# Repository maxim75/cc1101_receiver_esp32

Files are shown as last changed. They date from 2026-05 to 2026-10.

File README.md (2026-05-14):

# CC1101 + nRF24L01 Dual RF Receiver (ESP32-S3)

ESP32-S3 firmware that receives RF packets from two radios simultaneously and displays decoded data on an SH1107 128×128 OLED and serial monitor.

- **CC1101** — 433.92 MHz OOK packets from an ATtiny3226 transmitter (ELECHOUSE SmartRC-compatible protocol)
- **nRF24L01** — 2.4 GHz packets at 250 kbps, PA MAX

## Hardware

**Board:** ESP32-S3-DevKitC-1 (16 MB flash, PSRAM, native USB CDC)

### Wiring

| Peripheral | Signal | GPIO |
|---|---|---|
| CC1101 | SCK | 12 (FSPI/SPI2) |
| | MOSI | 11 |
| | MISO | 13 |
| | CSN | 10 |
| | GDO0 | 2 (interrupt) |
| nRF24L01 | SCK | 14 (HSPI/SPI3) |
| | MOSI | 1 |
| | MISO | 21 |
| | CSN | 6 |
| | CE | 5 |
| | IRQ | 4 (wired, not used) |
| SH1107 | SDA | 8 |
| | SCL | 9 |

All peripherals: VCC → 3.3 V, GND → GND

## Build & Flash

Requires [PlatformIO](https://platformio.org/).

```bash
# Build only
pio run

# Flash
pio run --target upload

# Flash and open serial monitor
pio run --target upload && pio device monitor

# Serial monitor only (115200 baud)
pio device monitor
```

## Dependencies

Managed automatically by PlatformIO:

| Library | Purpose |
|---|---|
| `jgromes/RadioLib` | CC1101 driver |
| `nrf24/RF24` | nRF24L01 driver |
| `olikraus/U8g2` | SH1107 OLED driver |
| `bblanchon/ArduinoJson` | JSON (available, not yet used) |

## How It Works

All firmware lives in `src/main.cpp`.

**CC1101** — interrupt-driven: GDO0 RISING edge sets a flag; `loop()` reads the packet with RadioLib, re-arms `startReceive()`, then calls `getRSSI()`.

**nRF24L01** — polled: `loop()` calls `nrf24.available()` each iteration; no re-arm needed.

Both radios share the same `PacketInfo` struct (`source`, hex, ASCII, RSSI, count). After each packet the OLED and serial monitor are updated; the OLED header shows which radio sourced the last packet.

**SPI:** CC1101 on FSPI (`SPI`), nRF24 on HSPI (`hspi`) — separate buses, no CS conflicts.

## Serial Output

Each received packet is logged at 115200 baud:

```
[CC1101] #1 | RSSI: -72 dBm | HEX: D3 91 04 AB CD | ASCII: ...
[nRF24]  #2 | HEX: 48 65 6C 6C 6F     | ASCII: Hello
```

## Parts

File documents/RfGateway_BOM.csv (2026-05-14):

Reference | Qty | Value | DNP | Exclude from BOM | Exclude from Board | Footprint | Datasheet
C1,C2,C3,C11,C12,C13 | 6 | 100nF |  |  |  | Capacitor_SMD:C_0805_2012Metric_Pad1.18x1.45mm_HandSolder
C4 | 1 | 22uF |  |  |  | Capacitor_SMD:C_0805_2012Metric_Pad1.18x1.45mm_HandSolder
C5,C6,C7,C8,C9,C10 | 6 | 1uF |  |  |  | Capacitor_SMD:C_0805_2012Metric_Pad1.18x1.45mm_HandSolder
C14,C15,C16 | 3 | 10uF |  |  |  | PCM_Capacitor_THT_AKL:CP_Radial_D5.0mm_P2.00mm
C17,C18 | 2 | 15pF |  |  |  | Capacitor_SMD:C_0805_2012Metric_Pad1.18x1.45mm_HandSolder
CN1 | 1 | I2C |  |  |  | easyeda2kicad:CONN-SMD_HCZZ0451-4
CN2 | 1 | X2026WV-2*02-N0SN |  |  |  | easyeda2kicad:CONN-TH_X2026WV-2X02-N0SN | https://lcsc.com/product-detail/Wire-To-Board-Wire-To-Wire-Connector_XKB-Enterprise-X2026WV-2-02-N0SN_C406181.html
CN4 | 1 | HX-PH2.0-6AWB |  |  |  | easyeda2kicad:CONN-SMD_HX-PH2.0-6AWB
D1 | 1 | SS14 |  |  |  | PCM_Diode_SMD_AKL:D_SMA | https://www.tme.eu/Document/39e1c2d2c354f63d74e9a2edb2156b4b/SS14-E3_61T.pdf
FPC1 | 1 | PH-2PWB |  |  |  | easyeda2kicad:FPC-SMD_2P-P2.00_DEALON_PH-2PWB
R1,R2 | 2 | 5.1K |  |  |  | Resistor_SMD:R_0805_2012Metric_Pad1.20x1.40mm_HandSolder
R3,R4,R5 | 3 | 10K |  |  |  | Resistor_SMD:R_0805_2012Metric_Pad1.20x1.40mm_HandSolder
SW1 | 1 | FLASH |  |  |  | easyeda2kicad:SW-SMD_4P-L4.5-W4.5-P3.00-LS7.5
SW2 | 1 | RESET |  |  |  | easyeda2kicad:SW-SMD_4P-L4.5-W4.5-P3.00-LS7.5
U1 | 1 | ESP32-S3-WROOM-2 |  |  |  | RF_Module:ESP32-S3-WROOM-2 | https://www.espressif.com/sites/default/files/documentation/esp32-s3-wroom-2_datasheet_en.pdf
U2 | 1 | E01C-ML01SP4 |  |  |  | easyeda2kicad:COMM-SMD_E01C-ML01SP4
U3 | 1 | E07-400M10S |  |  |  | easyeda2kicad:COMM-SMD_E07-400M10S
U4 | 1 | GT-USB-7010ASV |  |  |  | easyeda2kicad:USB-C-SMD_G-SWITCH_GT-USB-7010ASV
U5,U6 | 2 | MCP1700T-3302E-TT |  |  |  | PCM_Package_TO_SOT_SMD_AKL:SOT-23 | https://ww1.microchip.com/downloads/en/DeviceDoc/MCP1700-Low-Quiescent-Current-LDO-20001826E.pdf
U7 | 1 | ME6211C33M5 |  |  |  | Package_TO_SOT_SMD:SOT-23-5 | https://www.lcsc.com/datasheet/lcsc_datasheet_2304140030_MICRONE-Nanjing-Micro-One-Elec-ME6211C33R5G_C235316.pdf
U8 | 1 | E220-900T22S |  |  |  | easyeda2kicad:WIRELM-SMD_E220-900T22S | https://lcsc.com/product-detail/Wireless-Modules_Chengdu-Ebyte-Elec-Tech-E220-900T22S_C970285.html
Y1 | 1 | 32K |  |  |  | Crystal:Crystal_AT310_D3.0mm_L10.0mm_Horizontal

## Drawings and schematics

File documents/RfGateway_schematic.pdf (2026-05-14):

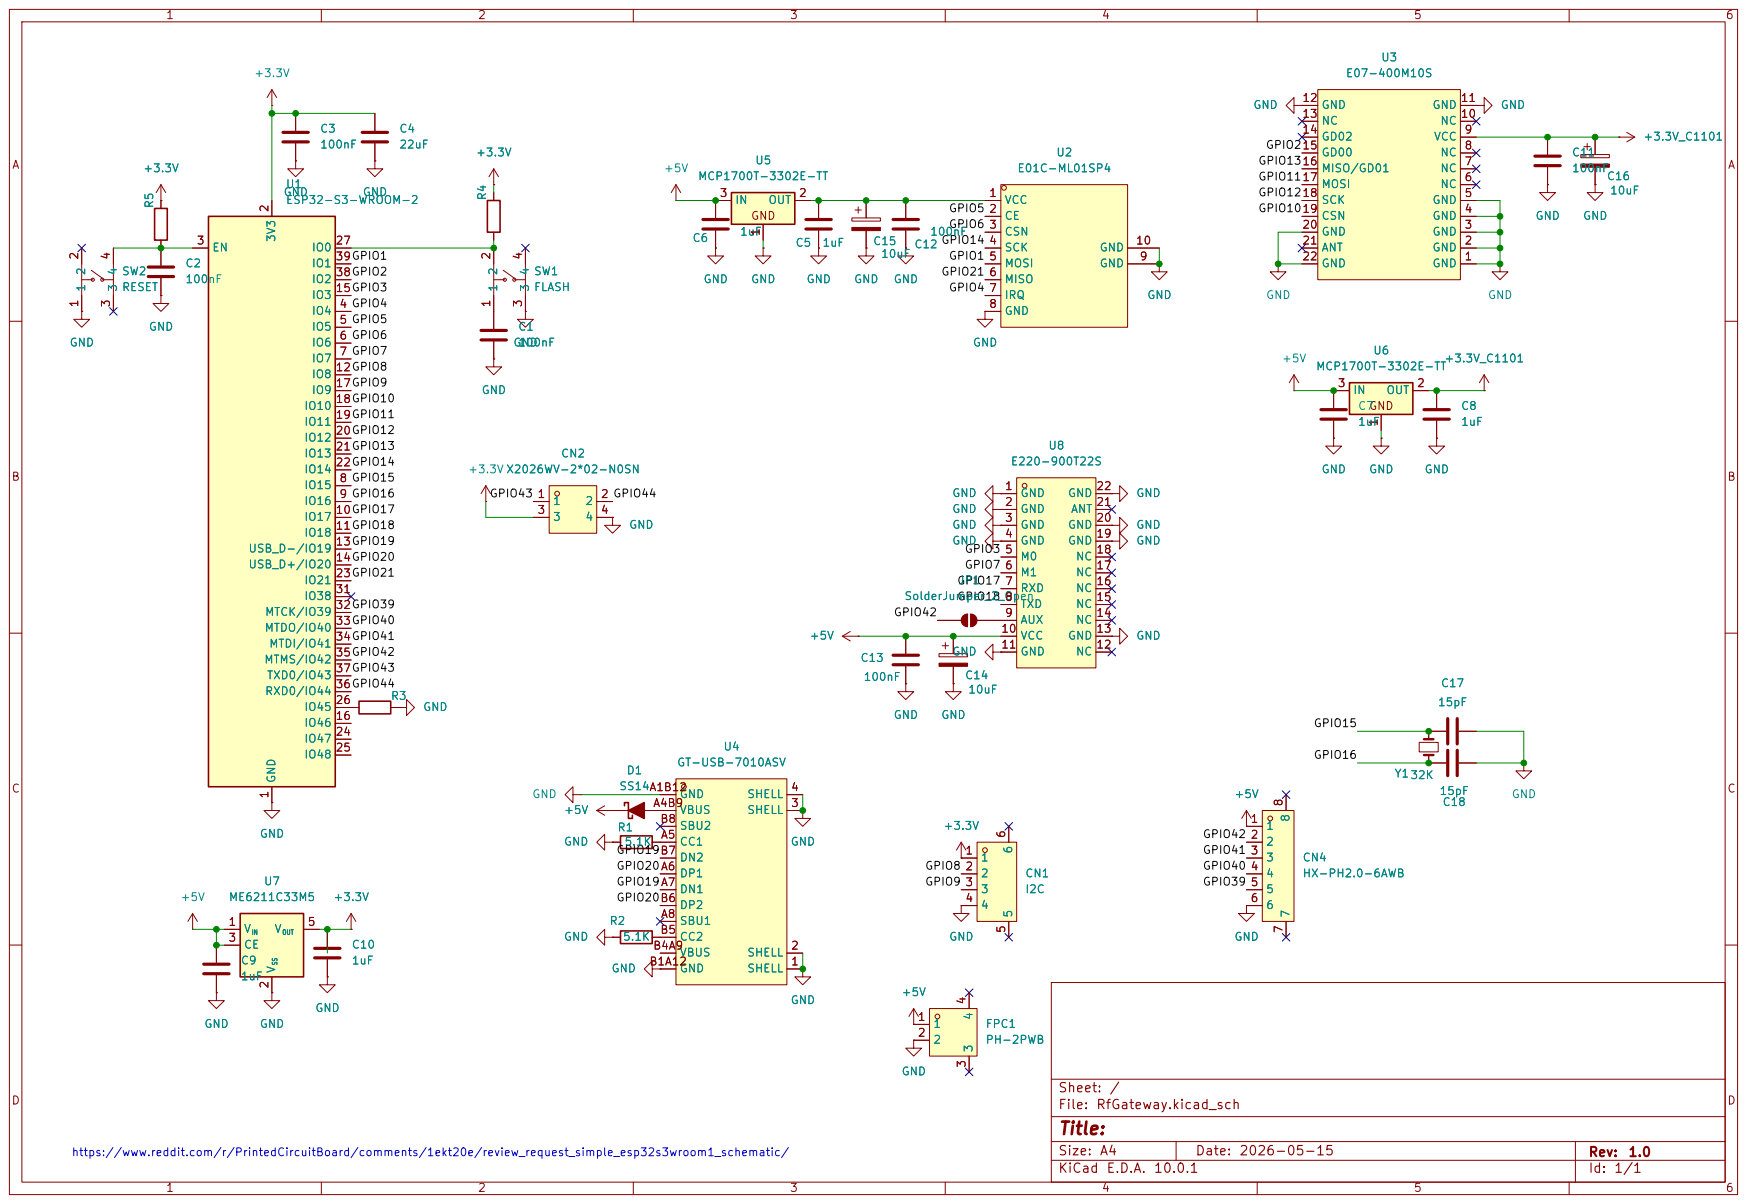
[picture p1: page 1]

IO38 31 MTCK/IO39 32 MTDO/IO40 33 MTDI/IO41 34 MTMS/IO42 35 RXD0/IO44 36 TXD0/IO43 37

https://www.reddit.com/r/PrintedCircuitBoard/comments/1ekt20e/review_request_simple_esp32s3wroom1_schematic/ +3.3V C10

Size: A4 | Rev: 1.0
KiCad E.D.A. 10.0.1 | Id: 1/1

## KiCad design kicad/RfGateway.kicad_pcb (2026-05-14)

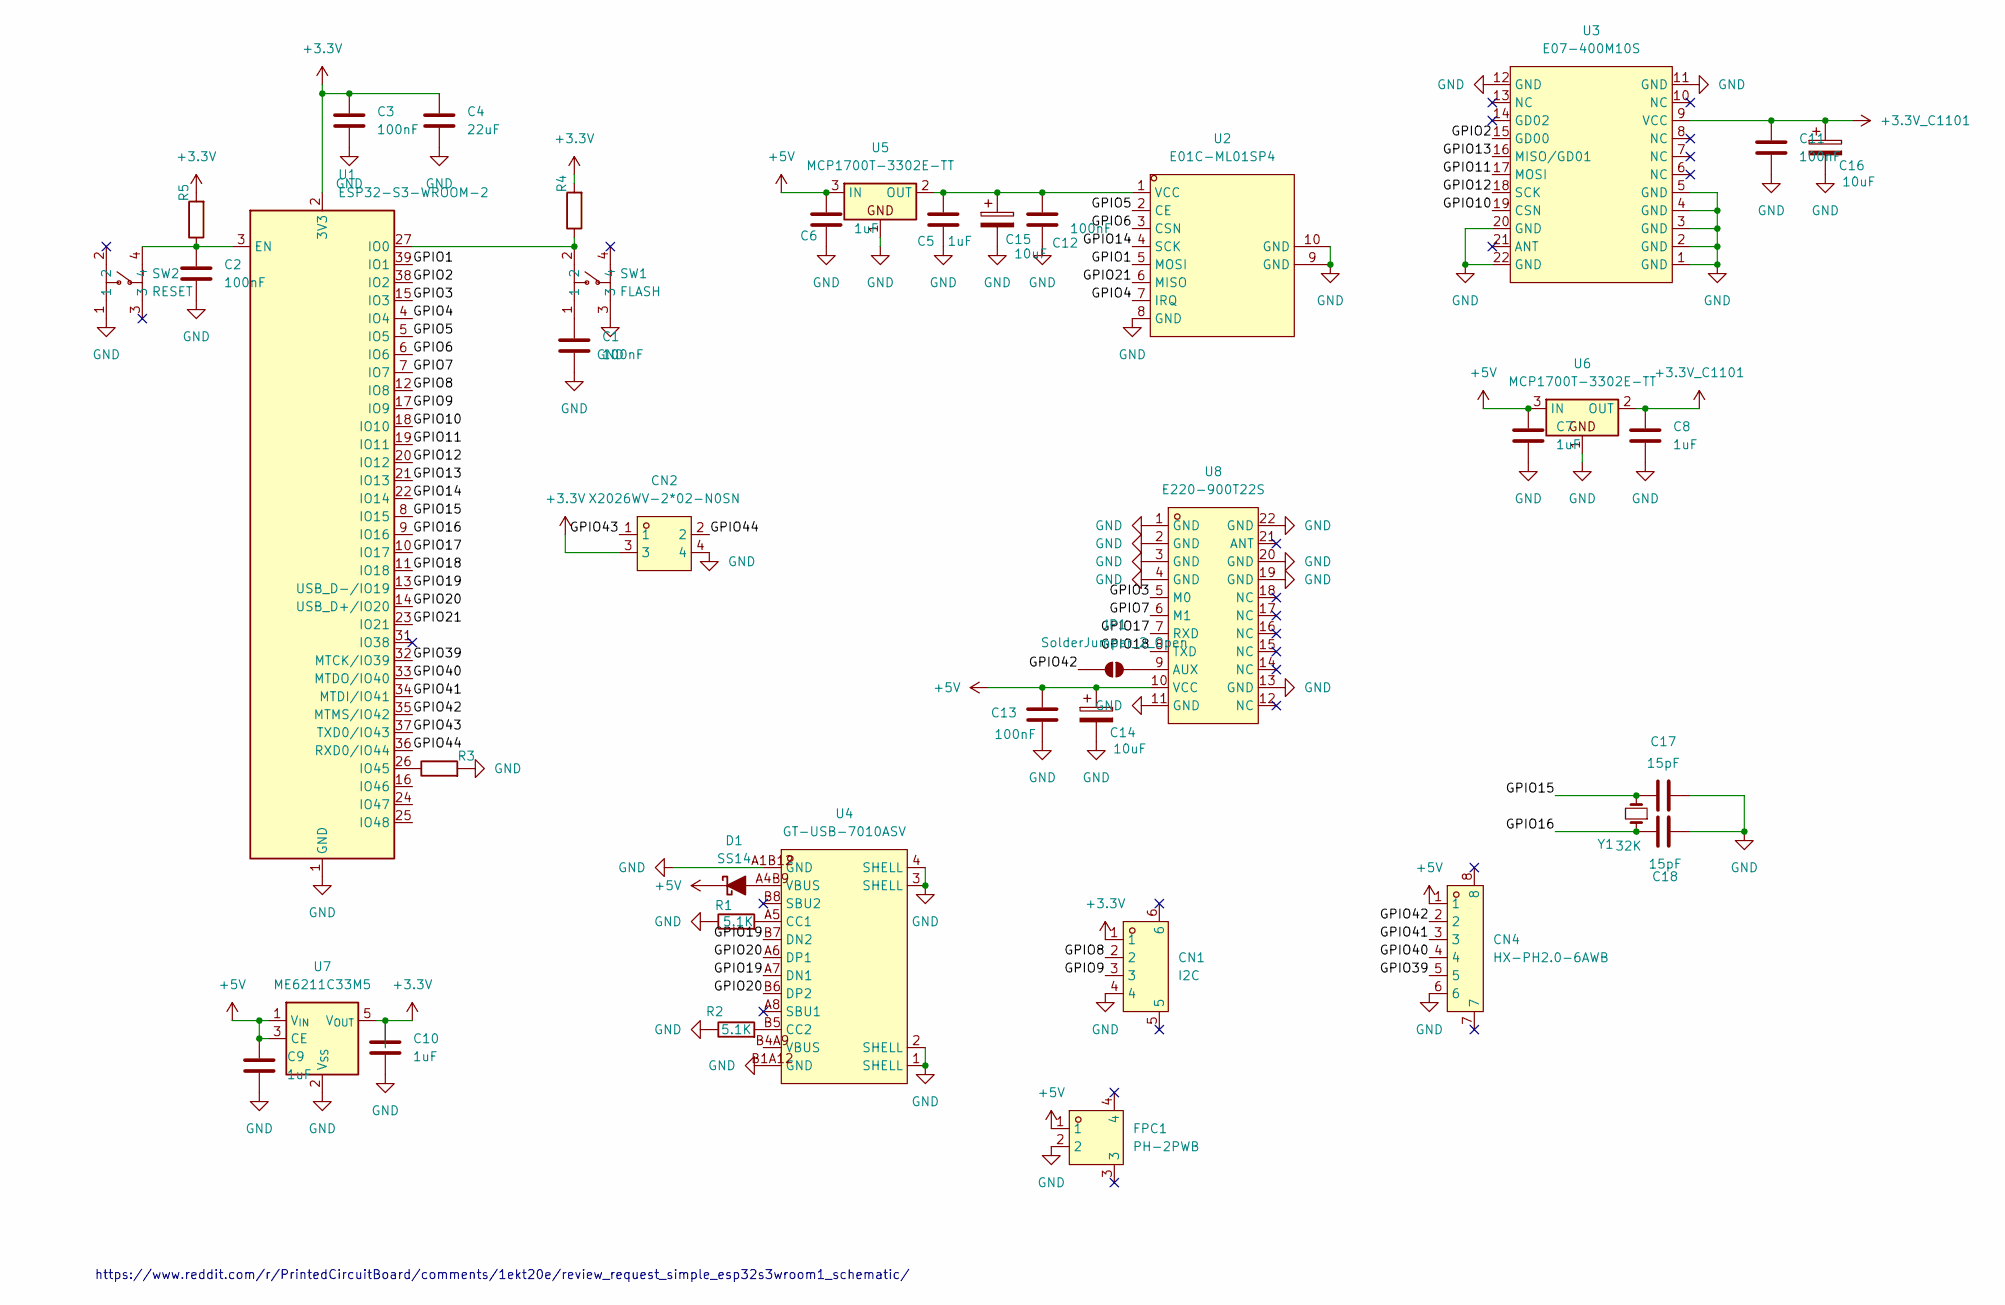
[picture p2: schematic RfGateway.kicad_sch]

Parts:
C1, C2, C3, C11, C12, C13: 100nF; C_0805_2012Metric_Pad1.18x1.45mm_HandSolder
C4: 22uF; C_0805_2012Metric_Pad1.18x1.45mm_HandSolder
C5, C6, C7, C8, C9, C10: 1uF; C_0805_2012Metric_Pad1.18x1.45mm_HandSolder
C14, C15, C16: 10uF; CP_Radial_D5.0mm_P2.00mm
C17, C18: 15pF; C_0805_2012Metric_Pad1.18x1.45mm_HandSolder
CN1: I2C; CONN-SMD_HCZZ0451-4; LCSC Part C7433650
CN2: X2026WV-2*02-N0SN; CONN-TH_X2026WV-2X02-N0SN; LCSC Part C406181
CN4: HX-PH2.0-6AWB; CONN-SMD_HX-PH2.0-6AWB; LCSC Part C52016430
D1: SS14; D_SMA
FPC1: PH-2PWB; FPC-SMD_2P-P2.00_DEALON_PH-2PWB; LCSC Part C2905019
JP1: SolderJumper_2_Open; SolderJumper-2_P1.3mm_Open_Pad1.0x1.5mm
R1, R2: 5.1K; R_0805_2012Metric_Pad1.20x1.40mm_HandSolder
R3, R4, R5: 10K; R_0805_2012Metric_Pad1.20x1.40mm_HandSolder
SW1: FLASH; SW-SMD_4P-L4.5-W4.5-P3.00-LS7.5; LCSC Part C22375348
SW2: RESET; SW-SMD_4P-L4.5-W4.5-P3.00-LS7.5; LCSC Part C22375348
U1: ESP32-S3-WROOM-2
U2: E01C-ML01SP4; COMM-SMD_E01C-ML01SP4; LCSC Part C2965508
U3: E07-400M10S; COMM-SMD_E07-400M10S; LCSC Part C2965513
U4: GT-USB-7010ASV; USB-C-SMD_G-SWITCH_GT-USB-7010ASV; LCSC Part C2988369
U5, U6: MCP1700T-3302E-TT; SOT-23
U7: ME6211C33M5; SOT-23-5
U8: E220-900T22S; WIRELM-SMD_E220-900T22S; LCSC Part C970285
Y1: 32K; Crystal_AT310_D3.0mm_L10.0mm_Horizontal

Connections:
+3.3V: C3.1, C4.1, C10.1, CN1.1, CN2.3, R4.2, R5.2, U1.2 (3V3), U7.5 (V_{OUT})
+3.3V_C1101: C8.1, C11.1, C16.1, U3.9 (VCC), U6.2 (OUT)
+5V: C6.1, C7.1, C9.1, C13.1, C14.1, CN4.1, D1.1 (K), FPC1.1, U5.3 (IN), U6.3 (IN), U7.1 (V_{IN}), U7.3 (CE), U8.10 (VCC)
/GPIO1: U1.39 (IO1), U2.5 (MOSI)
/GPIO2: U1.38 (IO2), U3.15 (GD00)
/GPIO3: U1.15 (IO3), U8.5 (M0)
/GPIO4: U1.4 (IO4), U2.7 (IRQ)
/GPIO5: U1.5 (IO5), U2.2 (CE)
/GPIO6: U1.6 (IO6), U2.3 (CSN)
/GPIO7: U1.7 (IO7), U8.6 (M1)
/GPIO8: CN1.2, U1.12 (IO8)
/GPIO9: CN1.3, U1.17 (IO9)
/GPIO10: U1.18 (IO10), U3.19 (CSN)
/GPIO11: U1.19 (IO11), U3.17 (MOSI)
/GPIO12: U1.20 (IO12), U3.18 (SCK)
/GPIO13: U1.21 (IO13), U3.16 (MISO/GD01)
/GPIO14: U1.22 (IO14), U2.4 (SCK)
/GPIO15: C17.1, U1.8 (IO15), Y1.2
/GPIO16: C18.1, U1.9 (IO16), Y1.1
/GPIO17: U1.10 (IO17), U8.7 (RXD)
/GPIO18: U1.11 (IO18), U8.8 (TXD)
/GPIO19: U1.13 (USB_D-/IO19), U4.A7 (DN1), U4.B7 (DN2)
/GPIO20: U1.14 (USB_D+/IO20), U4.A6 (DP1), U4.B6 (DP2)
/GPIO21: U1.23 (IO21), U2.6 (MISO)
/GPIO39: CN4.5, U1.32 (MTCK/IO39)
/GPIO40: CN4.4, U1.33 (MTDO/IO40)
/GPIO41: CN4.3, U1.34 (MTDI/IO41)
/GPIO42: CN4.2, JP1.1 (A), U1.35 (MTMS/IO42)
/GPIO43: CN2.1, U1.37 (TXD0/IO43)
/GPIO44: CN2.2, U1.36 (RXD0/IO44)
GND: C1.2, C2.2, C3.2, C4.2, C5.2, C6.2, C7.2, C8.2, C9.2, C10.2, C11.2, C12.2, C13.2, C14.2, C15.2, C16.2, C17.2, C18.2, CN1.4, CN2.4, CN4.6, FPC1.2, R1.1, R2.1, R3.2, SW1.3, SW2.1, U1.1 (GND), U1.40 (GND), U1.41 (GND), U2.8 (GND), U2.9 (GND), U2.10 (GND), U3.1 (GND), U3.2 (GND), U3.3 (GND), U3.4 (GND), U3.5 (GND), U3.11 (GND), U3.12 (GND), U3.20 (GND), U3.22 (GND), U4.1 (SHELL), U4.2 (SHELL), U4.3 (SHELL), U4.4 (SHELL), U4.A1B12 (GND), U4.B1A12 (GND), U5.1, U6.1, U7.2 (V_{SS}), U8.1 (GND), U8.2 (GND), U8.3 (GND), U8.4 (GND), U8.11 (GND), U8.13 (GND), U8.19 (GND), U8.20 (GND), U8.22 (GND)
unnamed: C1.1, SW1.1
unnamed: D1.2 (A), U4.A4B9 (VBUS)
unnamed: JP1.2 (B), U8.9 (AUX)
unnamed: C2.1, R5.1, SW2.4, U1.3 (EN)
unnamed: R4.1, SW1.2, U1.27 (IO0)
unnamed: R3.1, U1.26 (IO45)
unnamed: C5.1, C12.1, C15.1, U2.1 (VCC), U5.2 (OUT)
unnamed: R1.2, U4.A5 (CC1)
unnamed: R2.2, U4.B5 (CC2)

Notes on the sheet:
https://www.reddit.com/r/PrintedCircuitBoard/comments/1ekt20e/review_request_simple_esp32s3wroom1_schematic/

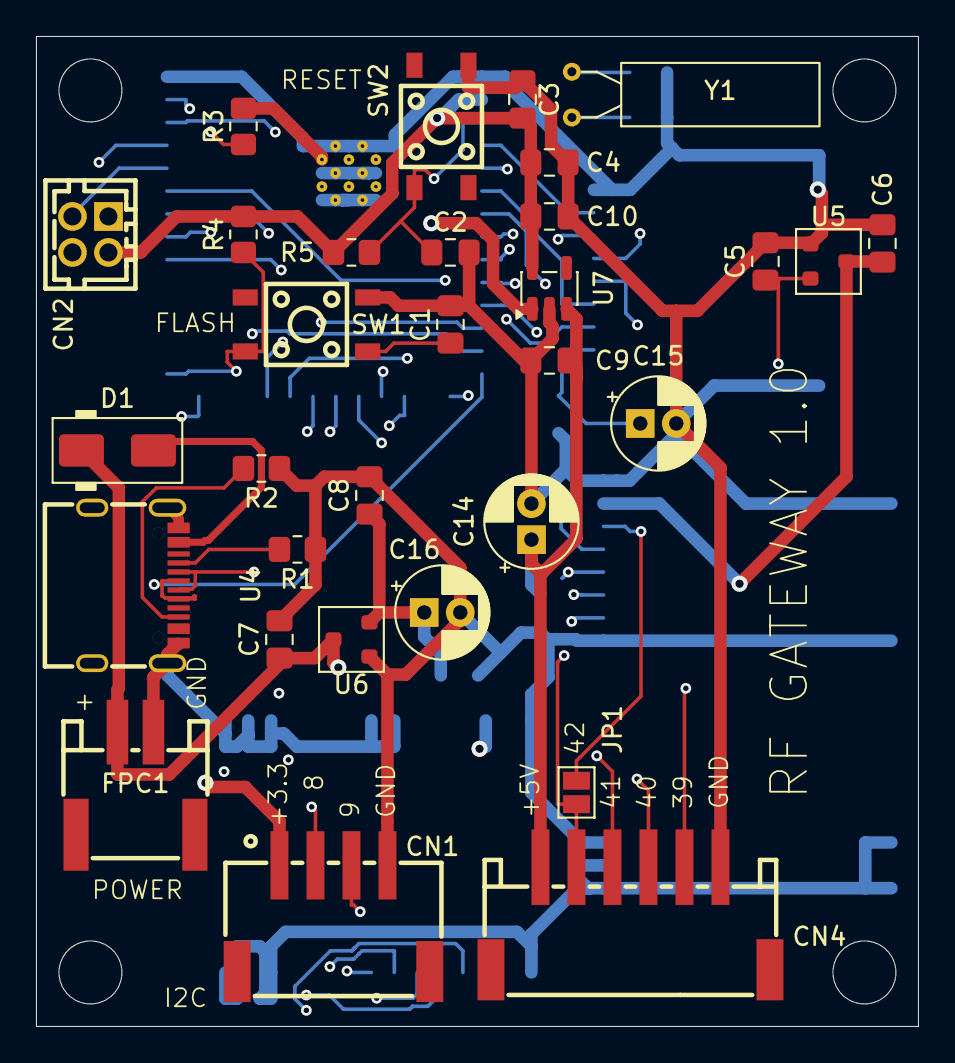
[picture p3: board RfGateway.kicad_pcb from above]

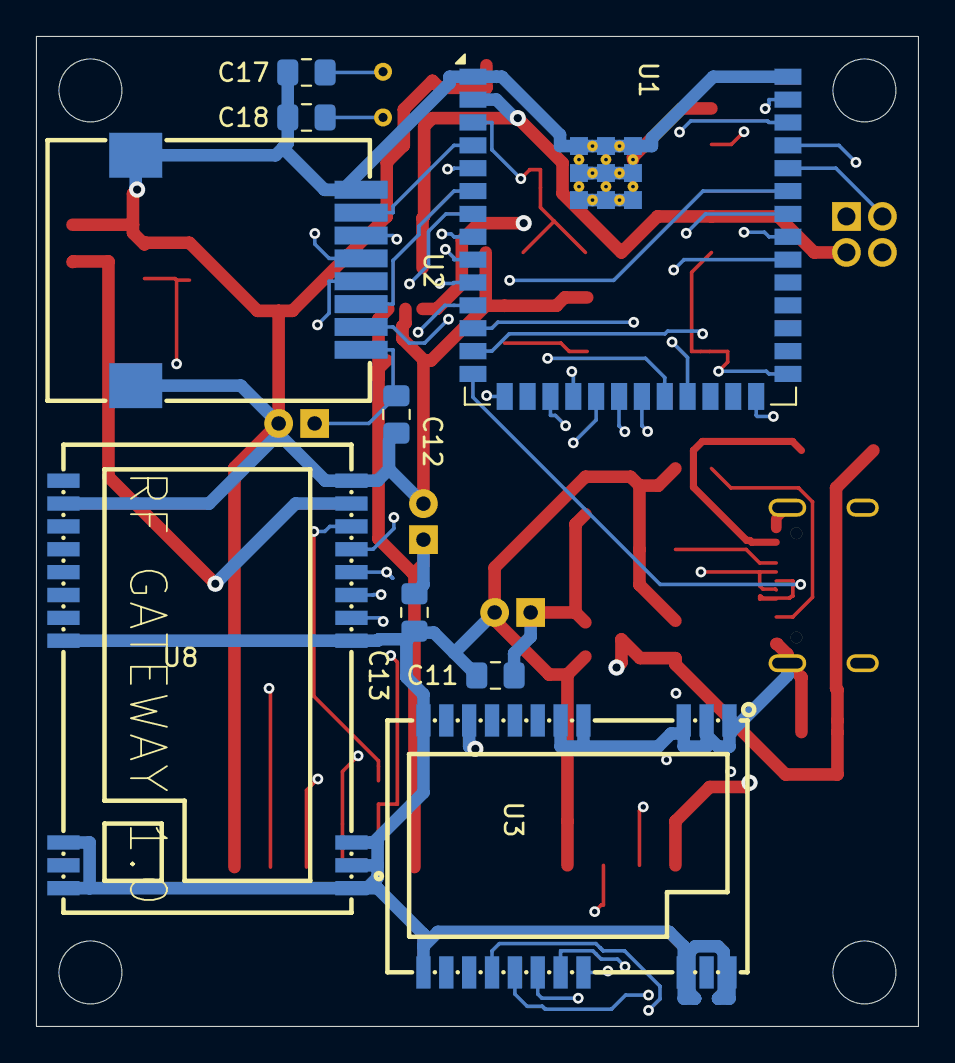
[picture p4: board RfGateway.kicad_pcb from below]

Board: 4 copper layers, 49.0 x 55.0 mm, 40 parts (9 on the bottom side), 40 nets.

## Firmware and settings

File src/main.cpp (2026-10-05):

/**
 * @file    main.cpp
 * @brief   ESP32-S3 + CC1101 + nRF24L01 dual RF receiver with SH1107 OLED display.
 *
 * CC1101  — receives fixed-code 433 MHz remotes (EV1527/PT2262) in async OOK mode;
 *           demodulated pulses on GDO0 are decoded by rc-switch.
 * nRF24L01— receives 2.4 GHz packets on a dedicated HSPI bus.
 * Decoded packet details (hex, ASCII or remote code info, RSSI where available)
 * are shown on the OLED and serial port, and published to MQTT for Home Assistant
 * (remotes: rfgateway/remote JSON; nRF24: nrf/message plain text).
 *
 * Libraries
 *   RadioLib  — jgromes/RadioLib   (CC1101)
 *   rc-switch — sui77/rc-switch    (remote pulse decoding)
 *   RF24      — nrf24/RF24          (nRF24L01)
 *   U8g2      — olikraus/U8g2
 *   PubSubClient — knolleary/PubSubClient (MQTT)
 *   ArduinoJson  — bblanchon/ArduinoJson  (HA discovery payloads)
 *
 * Credentials: copy include/secrets.example.h to include/secrets.h (gitignored).
 *
 * Wiring
 *   Peripheral  Signal  ESP32-S3 GPIO
 *   ─────────────────────────────────
 *   CC1101      SCK     12  ┐
 *               MOSI    11  │ FSPI bus (SPI2)
 *               MISO    13  ┘
 *               CSN     10
 *               GDO0     2   (async OOK data out, CHANGE interrupt)
 *   nRF24L01    SCK     14  ┐
 *               MOSI     1  │ HSPI bus (SPI3)
 *               MISO    21  ┘
 *               CSN      6
 *               CE       5
 *               IRQ      4   (packet interrupt, FALLING)
 *   SH1107      SDA      8
 *               SCL      9
 *   All         VCC     3.3V
 *               GND     GND
 */

#include <RadioLib.h>
#include <RCSwitch.h>
#include <RF24.h>
#include <nRF24L01.h>
#include <SPI.h>
#include <U8g2lib.h>
#include <WiFi.h>
#include <PubSubClient.h>
#include <ArduinoJson.h>

#if __has_include("secrets.h")
#include "secrets.h"
#else
#error "include/secrets.h missing: copy include/secrets.example.h to include/secrets.h and fill it in"
#endif

// ---------------------------------------------------------------------------
// Hardware configuration
// ---------------------------------------------------------------------------

namespace Pin {
    // FSPI bus (SPI2) — CC1101
    constexpr int SCK  = 12;
    constexpr int MISO = 13;
    constexpr int MOSI = 11;

    // CC1101
    constexpr int CC_CS   = 10;
    constexpr int CC_GDO0 =  2;

    // HSPI bus (SPI3) — nRF24L01
    constexpr int NRF_SCK  = 14;
    constexpr int NRF_MOSI =  1;
    constexpr int NRF_MISO = 21;

    // nRF24L01
    constexpr int NRF_CS  =  6;
    constexpr int NRF_CE  =  5;
    constexpr int NRF_IRQ =  4;

    // SH1107 (I2C)
    constexpr int OLED_SDA = 8;
    constexpr int OLED_SCL = 9;
}

namespace Radio {
    constexpr float    FREQUENCY_MHZ  = 433.92f;
    constexpr float    BITRATE_KBPS   =   9.6f;    // finer edge timing in async mode
    constexpr float    DEVIATION_KHZ  =   5.157f;
    constexpr float    RXBW_KHZ       = 270.0f;    // tolerate drift of cheap remotes
    constexpr int      POWER_DBM      =  10;
    constexpr uint32_t REPEAT_GAP_MS  = 300;       // same code within this gap = same press
}

namespace Nrf {
    constexpr uint64_t ADDRESS         = 0xFAB7C2F0E2LL;  // must match transmitter
    constexpr uint32_t HEALTH_CHECK_MS = 1000;            // brownout-reset detection interval
}

namespace Mqtt {
    constexpr const char* CLIENT_ID    = "rfgateway";
    constexpr const char* TOPIC_STATUS = "rfgateway/status";   // retained online/offline (LWT)
    constexpr const char* TOPIC_REMOTE = "rfgateway/remote";   // JSON per remote press
    constexpr const char* TOPIC_NRF    = "nrf/message";        // same as legacy nrf_receiver
    constexpr uint32_t    RETRY_MS     = 5000;
    constexpr uint16_t    BUFFER_SIZE  = 512;                  // fits HA discovery payloads
}

namespace Display {
    constexpr uint8_t WIDTH        = 128;
    constexpr uint8_t HEIGHT       = 128;
    constexpr uint8_t LOG_ROWS     =  10;   // message lines below the header
    constexpr uint8_t LOG_TOP      =  25;   // y of first log row
    constexpr uint8_t ROW_HEIGHT   =  10;
    constexpr uint8_t LOG_CHARS    =  16;   // content chars per row after "HH:MM:SS "
}

namespace Clock {
    constexpr const char* TZ_SYDNEY   = "AEST-10AEDT,M10.1.0,M4.1.0/3";
    constexpr const char* NTP_SERVER  = "pool.ntp.org";
    constexpr time_t      VALID_AFTER = 1700000000;   // earlier = not yet NTP-synced
}

// ---------------------------------------------------------------------------
// Peripherals
// ---------------------------------------------------------------------------
CC1101    cc1101 = new Module(Pin::CC_CS, Pin::CC_GDO0, RADIOLIB_NC, RADIOLIB_NC);
RCSwitch  rcSwitch;
SPIClass  hspi(HSPI);
RF24      nrf24(Pin::NRF_CE, Pin::NRF_CS);
WiFiClient   wifiClient;
PubSubClient mqtt(wifiClient);

// SH1107 panels differ in column mapping; SEEED variant avoids left/right wrap artifacts.
U8G2_SH1107_SEEED_128X128_F_HW_I2C display(
    U8G2_R3, U8X8_PIN_NONE, Pin::OLED_SCL, Pin::OLED_SDA);   // R3 = rotated 270° clockwise

// ---------------------------------------------------------------------------
// Application state
// ---------------------------------------------------------------------------

struct PacketInfo {
    char     source[8]  = {};
    char     ascii[22]  = {};
    float    rssi       = 0.0f;
    uint32_t count      = 0;
    bool     hasRssi    = false;
};

struct LogEntry {
    time_t received = 0;     // 0 = clock was not synced yet
    char   text[24] = {};
};

static PacketInfo lastPacket;
static LogEntry      msgLog[Display::LOG_ROWS];   // [0] = newest
static uint8_t       msgCount      = 0;
static bool          screenDirty   = true;
static time_t        lastDrawnSec  = 0;
static unsigned long lastRemoteCode   = 0;
static uint32_t      lastRemoteSeenMs = 0;
static uint32_t      lastMqttAttemptMs = 0;
static bool          wifiWasUp         = false;
static uint32_t      lastNrfCheckMs    = 0;

// ---------------------------------------------------------------------------
// Display helpers
// ---------------------------------------------------------------------------

static void drawCenteredText(uint8_t y, const char* text) {
    int16_t x = (Display::WIDTH - display.getStrWidth(text)) / 2;
    if (x < 0) x = 0;
    display.drawStr((uint8_t)x, y, text);
}

static void displaySplash(const char* line1, const char* line2 = nullptr) {
    display.clearBuffer();
    display.setFont(u8g2_font_6x10_tr);
    drawCenteredText(54, line1);
    if (line2) drawCenteredText(74, line2);
    display.sendBuffer();
}

static void formatTime(time_t t, char* out, size_t outSize) {
    if (t < Clock::VALID_AFTER) { snprintf(out, outSize, "--:--:--"); return; }
    struct tm local;
    localtime_r(&t, &local);
    strftime(out, outSize, "%H:%M:%S", &local);
}

// Connection indicator: filled dot = up, hollow dot = down
static void drawStatus(uint8_t x, uint8_t baseline, const char* label, bool up) {
    if (up) display.drawDisc(x + 3, baseline - 4, 3);
    else    display.drawCircle(x + 3, baseline - 4, 3);
    display.drawStr(x + 9, baseline, label);
}

static void addMessage(const char* text) {
    memmove(&msgLog[1], &msgLog[0], sizeof(LogEntry) * (Display::LOG_ROWS - 1));
    const time_t now = time(nullptr);
    msgLog[0].received = now >= Clock::VALID_AFTER ? now : 0;
    snprintf(msgLog[0].text, sizeof(msgLog[0].text), "%s", text);
    if (msgCount < Display::LOG_ROWS) msgCount++;
    screenDirty = true;
}

// Header (IP, Wi-Fi/MQTT status, clock) above a rolling log, newest row inverted.
static void drawScreen() {
    char timeStr[12];
    display.clearBuffer();
    display.setFontMode(1);   // transparent glyph background for inverted rows

    display.setFont(u8g2_font_6x10_tr);
    const bool wifiUp = WiFi.status() == WL_CONNECTED;
    display.drawStr(0, 9, wifiUp ? WiFi.localIP().toString().c_str() : "Wi-Fi connecting...");
    drawStatus(0,  20, "WiFi", wifiUp);
    drawStatus(39, 20, "MQTT", mqtt.connected());
    formatTime(time(nullptr), timeStr, sizeof(timeStr));
    display.drawStr(Display::WIDTH - display.getStrWidth(timeStr), 20, timeStr);
    display.drawHLine(0, 23, Display::WIDTH);

    display.setFont(u8g2_font_5x8_tr);
    if (msgCount == 0) drawCenteredText(Display::LOG_TOP + 4 * Display::ROW_HEIGHT, "Listening...");

    for (uint8_t i = 0; i < msgCount; i++) {
        const uint8_t top = Display::LOG_TOP + i * Display::ROW_HEIGHT;
        if (i == 0) {
            display.drawBox(0, top, Display::WIDTH, Display::ROW_HEIGHT);
            display.setDrawColor(0);
        }

        char content[Display::LOG_CHARS + 1];
        snprintf(content, sizeof(content), "%s", msgLog[i].text);
        if (strlen(msgLog[i].text) > Display::LOG_CHARS) {
            content[Display::LOG_CHARS - 2] = '.';
            content[Display::LOG_CHARS - 1] = '.';
        }
        formatTime(msgLog[i].received, timeStr, sizeof(timeStr));
        display.drawStr(1,  top + 8, timeStr);
        display.drawStr(46, top + 8, content);   // 9 chars * 5 px + 1

        display.setDrawColor(1);
    }

    display.sendBuffer();
}

// ---------------------------------------------------------------------------
// Radio helpers
// ---------------------------------------------------------------------------

// Full nRF24 configuration. Also used to recover after a supply brownout resets
// the module to power-on defaults (2 Mbps, powered down), which stops reception.
static bool initNrf24() {
    if (!nrf24.begin(&hspi)) return false;
    nrf24.setDataRate(RF24_250KBPS);
    nrf24.openReadingPipe(0, Nrf::ADDRESS);
    nrf24.setPALevel(RF24_PA_MAX, true);
    nrf24.startListening();
    return true;
}

static void buildAsciiString(const uint8_t* data, int len, char* out, size_t outSize) {
    int maxChars = min(len, (int)(outSize - 1));
    for (int i = 0; i < maxChars; i++) {
        out[i] = isprint(data[i]) ? (char)data[i] : '.';
    }
    out[maxChars] = '\0';
}

static void fillPacket(PacketInfo& pkt, const char* source,
                       const uint8_t* buf, int len, float rssi, bool hasRssi) {
    pkt.count++;
    pkt.rssi    = rssi;
    pkt.hasRssi = hasRssi;
    strncpy(pkt.source, source, sizeof(pkt.source) - 1);
    pkt.source[sizeof(pkt.source) - 1] = '\0';
    buildAsciiString(buf, len, pkt.ascii, sizeof(pkt.ascii));
}

static void logPacketToSerial(const PacketInfo& pkt, const uint8_t* rawData, int len) {
    Serial.printf("── [%s] Packet %lu (%d bytes) ──────────\n", pkt.source, pkt.count, len);
    Serial.print("  Hex:   ");
    for (int i = 0; i < len; i++) Serial.printf("%02X ", rawData[i]);
    Serial.println();
    Serial.printf("  ASCII: \"%s\"\n", pkt.ascii);
    if (pkt.hasRssi) Serial.printf("  RSSI:  %.1f dBm\n", pkt.rssi);
    Serial.println("─────────────────────────────────────────\n");
}

static void logRemoteToSerial(const PacketInfo& pkt, unsigned long code,
                              unsigned int bits, unsigned int protocol, unsigned int pulseUs) {
    Serial.printf("── [%s] Press %lu ──────────\n", pkt.source, pkt.count);
    Serial.printf("  Code:     %lu (0x%lX)\n", code, code);
    Serial.printf("  Bits:     %u\n", bits);
    Serial.printf("  Protocol: %u\n", protocol);
    Serial.printf("  Pulse:    %u us\n", pulseUs);
    Serial.printf("  RSSI:     %.1f dBm\n", pkt.rssi);
    Serial.println("─────────────────────────────────────────\n");
}

// ---------------------------------------------------------------------------
// MQTT / Home Assistant
// ---------------------------------------------------------------------------

// Announce a sensor via Home Assistant MQTT discovery (retained).
// valueTemplate == nullptr means the state topic carries plain text.
static void publishDiscoverySensor(const char* objectId, const char* name,
                                   const char* stateTopic, const char* valueTemplate) {
    char uniqueId[48];
    snprintf(uniqueId, sizeof(uniqueId), "%s_%s", Mqtt::CLIENT_ID, objectId);

    StaticJsonDocument<512> doc;
    doc["name"]               = name;
    doc["unique_id"]          = uniqueId;
    doc["state_topic"]        = stateTopic;
    doc["availability_topic"] = Mqtt::TOPIC_STATUS;
    if (valueTemplate) {
        doc["value_template"]        = valueTemplate;
        doc["json_attributes_topic"] = stateTopic;
    }
    JsonObject device = doc.createNestedObject("device");
    device.createNestedArray("identifiers").add(Mqtt::CLIENT_ID);
    device["name"] = "RF Gateway";

    char topic[80];
    snprintf(topic, sizeof(topic), "homeassistant/sensor/%s/%s/config", Mqtt::CLIENT_ID, objectId);
    char payload[Mqtt::BUFFER_SIZE];
    const size_t len = serializeJson(doc, payload, sizeof(payload));
    mqtt.publish(topic, (const uint8_t*)payload, len, true);
}

// Non-blocking Wi-Fi/MQTT upkeep; called every loop(). A connect attempt to an
// unreachable broker can block for a few seconds — radio events then are lost.
static void mqttMaintain() {
    const bool wifiUp = WiFi.status() == WL_CONNECTED;
    if (wifiUp != wifiWasUp) {
        wifiWasUp = wifiUp;
        if (wifiUp) Serial.printf("[WIFI] connected, IP %s\n", WiFi.localIP().toString().c_str());
        else        Serial.println("[WIFI] disconnected");
    }

    if (mqtt.connected()) { mqtt.loop(); return; }
    if (!wifiUp) return;

    const uint32_t now = millis();
    if (lastMqttAttemptMs != 0 && now - lastMqttAttemptMs < Mqtt::RETRY_MS) return;
    lastMqttAttemptMs = now;

    if (!mqtt.connect(Mqtt::CLIENT_ID, MQTT_USER, MQTT_PASSWORD,
                      Mqtt::TOPIC_STATUS, 0, true, "offline")) {
        Serial.printf("[MQTT] connect failed, rc=%d\n", mqtt.state());
        return;
    }
    Serial.println("[MQTT] connected");
    mqtt.publish(Mqtt::TOPIC_STATUS, "online", true);
    publishDiscoverySensor("remote_code",  "Last remote code",  Mqtt::TOPIC_REMOTE, "{{ value_json.code }}");
    publishDiscoverySensor("nrf24_packet", "Last nRF24 packet", Mqtt::TOPIC_NRF,    nullptr);
}

static void publishRemote(unsigned long code, unsigned int bits, unsigned int protocol,
                          unsigned int pulseUs, float rssi) {
    char payload[128];
    snprintf(payload, sizeof(payload),
             "{\"code\":%lu,\"bits\":%u,\"protocol\":%u,\"pulse\":%u,\"rssi\":%.0f}",
             code, bits, protocol, pulseUs, rssi);
    mqtt.publish(Mqtt::TOPIC_REMOTE, payload);
}

// Same format as the legacy nrf_receiver firmware: raw text up to the first NUL.
static void publishNrf(const uint8_t* data, int len) {
    char text[33] = {};
    memcpy(text, data, min(len, 32));
    mqtt.publish(Mqtt::TOPIC_NRF, text);
}

// ---------------------------------------------------------------------------
// Arduino entry points
// ---------------------------------------------------------------------------

void setup() {
    Serial.begin(115200);
    // Wait up to 3 s for USB CDC host (ESP32-S3 native USB)
    for (uint32_t t = millis(); !Serial && (millis() - t < 3000); ) delay(10);

    // OLED up first so errors are visible on screen
    display.begin();
    displaySplash("Dual RX", "Initializing...");

    Serial.println("\n==============================");
    Serial.println("  ESP32-S3 Dual RF Receiver");
    Serial.println("==============================");

    SPI.begin(Pin::SCK, Pin::MISO, Pin::MOSI);
    hspi.begin(Pin::NRF_SCK, Pin::NRF_MISO, Pin::NRF_MOSI, Pin::NRF_CS);

    // --- CC1101 ---
    int state = cc1101.begin(
        Radio::FREQUENCY_MHZ,
        Radio::BITRATE_KBPS,
        Radio::DEVIATION_KHZ,
        Radio::RXBW_KHZ,
        Radio::POWER_DBM);

    if (state != RADIOLIB_ERR_NONE) {
        char errMsg[24];
        snprintf(errMsg, sizeof(errMsg), "CC1101 err: %d", state);
        Serial.printf("[ERROR] CC1101 init failed: %d\n", state);
        displaySplash("CC1101 FAILED", errMsg);
        while (true) delay(1000);
    }

    cc1101.setOOK(true);
    cc1101.receiveDirectAsync();    // GDO0 now outputs raw demodulated OOK data
    rcSwitch.enableReceive(digitalPinToInterrupt(Pin::CC_GDO0));

    Serial.println("[OK] CC1101 ready");
    Serial.printf("  Frequency:  %.2f MHz\n",  Radio::FREQUENCY_MHZ);
    Serial.printf("  RX BW:      %.0f kHz\n",  Radio::RXBW_KHZ);
    Serial.println("  Modulation: OOK async | Decoder: rc-switch");

    // --- nRF24L01 ---
    if (!initNrf24()) {
        Serial.println("[ERROR] nRF24 init failed");
        displaySplash("nRF24 FAILED", "check wiring");
        while (true) delay(1000);
    }

    Serial.println("[OK] nRF24 ready");
    Serial.printf("  Address:    0x%010llX\n", Nrf::ADDRESS);
    Serial.println("  Data rate:  250 kbps | PA: MAX");

    // --- Wi-Fi / MQTT (connection happens in loop() so radios run immediately) ---
    WiFi.mode(WIFI_STA);
    WiFi.setAutoReconnect(true);
    WiFi.begin(WIFI_SSID, WIFI_PASSWORD);
    mqtt.setServer(MQTT_HOST, MQTT_PORT);
    mqtt.setBufferSize(Mqtt::BUFFER_SIZE);
    mqtt.setSocketTimeout(2);
    Serial.printf("[..] Wi-Fi \"%s\", MQTT %s:%d\n", WIFI_SSID, MQTT_HOST, MQTT_PORT);
    configTzTime(Clock::TZ_SYDNEY, Clock::NTP_SERVER);   // syncs once Wi-Fi is up

    Serial.println("\n[LISTENING]\n");

    drawScreen();  // shows "Listening..."
}

void loop() {
    mqttMaintain();

    if (rcSwitch.available()) {
        const unsigned long code     = rcSwitch.getReceivedValue();
        const unsigned int  bits     = rcSwitch.getReceivedBitlength();
        const unsigned int  protocol = rcSwitch.getReceivedProtocol();
        const unsigned int  pulseUs  = rcSwitch.getReceivedDelay();
        rcSwitch.resetAvailable();

        // Remotes repeat each frame many times per press; report a press once
        const uint32_t now = millis();
        const bool repeat = code == lastRemoteCode && now - lastRemoteSeenMs < Radio::REPEAT_GAP_MS;
        lastRemoteCode   = code;
        lastRemoteSeenMs = now;

        if (code != 0 && !repeat) {
            fillPacket(lastPacket, "Remote", nullptr, 0, cc1101.getRSSI(), true);
            char text[sizeof(LogEntry::text)];
            snprintf(text, sizeof(text), "RF %lu", code);
            addMessage(text);
            logRemoteToSerial(lastPacket, code, bits, protocol, pulseUs);
            publishRemote(code, bits, protocol, pulseUs, lastPacket.rssi);
        }
    }

    // A brownout reset restores the 2 Mbps default; re-apply our configuration
    if (millis() - lastNrfCheckMs >= Nrf::HEALTH_CHECK_MS) {
        lastNrfCheckMs = millis();
        if (nrf24.getDataRate() != RF24_250KBPS) {
            Serial.printf("[WARN] nRF24 reset detected, %s\n",
                          initNrf24() ? "reinitialised" : "reinit failed");
        }
    }

    if (nrf24.available()) {
        uint8_t buf[32] = {};
        uint8_t len = nrf24.getDynamicPayloadSize();
        if (len == 0 || len > sizeof(buf)) len = nrf24.getPayloadSize();
        if (len == 0 || len > sizeof(buf)) len = (uint8_t)sizeof(buf);
        nrf24.read(buf, len);

        fillPacket(lastPacket, "nRF24", buf, len, 0.0f, false);
        // Display text ends at the first NUL, like the MQTT payload (hides padding)
        char text[sizeof(LogEntry::text)];
        buildAsciiString(buf, (int)strnlen((const char*)buf, len), text, sizeof(text));
        addMessage(text);
        logPacketToSerial(lastPacket, buf, len);
        publishNrf(buf, len);
    }

    // Redraw on new messages and once per second for the clock and status
    const time_t nowSec = time(nullptr);
    if (screenDirty || nowSec != lastDrawnSec) {
        screenDirty  = false;
        lastDrawnSec = nowSec;
        drawScreen();
    }
}

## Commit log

2026-04-28 Migrate CC1101 driver from SmartRC to RadioLib
    Replace lsatan/SmartRC-CC1101-Driver-Lib with jgromes/RadioLib.
    Rewrite main.cpp to use RadioLib CC1101 API with interrupt-driven RX.
    [main.cpp]
2026-04-28 Switch to RadioLib for CC1101 receive
2026-04-29 Switch CC1101 SPI pins to ESP32-S3 standard FSPI (10/11/12/13)
2026-04-29 Update CLAUDE.md wiring table to match new FSPI pin assignments
2026-04-29 Fix nRF24 init: data rate is kbps (1000), not mode index (1)
    RadioLib nRF24::begin() takes int16_t freq (MHz) and int16_t dr (kbps).
    Valid rates are 250, 1000, 2000. Passing 1 caused RADIOLIB_ERR_INVALID_DATA_RATE (-501).
    [main.cpp]
2026-04-29 Fix nRF24 CE pin slot and lower SPI to 500 kHz
    RadioLib nRF24::begin() drives CE via getRst() (3rd Module arg), not getGpio()
    (4th arg). Also sets explicit SPISettings at 500 kHz to improve reliability.
    [main.cpp]
2026-04-29 Send ACTIVATE command before nRF24 begin() to unlock FEATURE register
    RadioLib writes to the FEATURE register inside begin() without sending the
    ACTIVATE (0x50, 0x73) command first. On nRF24L01 (non-plus), FEATURE is
    locked at power-on so the write is ignored; the SPI paranoid readback then
    mismatches and returns -16 (SPI_WRITE_FAILED). nRF24L01+ is unaffected.
2026-04-29 Switch nRF24 receiver to RF24 library
2026-04-29 Separate CC1101 and nRF24L01 onto dedicated SPI buses
    - Migrate CC1101 to FSPI (SPI2): GPIO 11/12/13 with CS on GPIO 10
    - Migrate nRF24L01 to HSPI (SPI3): GPIO 14/15/16 with CS on GPIO 6
    - Add SPIClass hspi instance and initialize in setup()
    - Update CLAUDE.md wiring table and architecture notes
    - Add VS Code extension recommendations
2026-04-29 fix: read actual nRF24 payload length via getDynamicPayloadSize/getPayloadSize
    Agent-Logs-Url: https://github.com/maxim75/cc1101_receiver_esp32/sessions/2e9f2deb-e697-4acf-9f65-a31d00ca5fc1
    [main.cpp]
2026-04-29 fix: add uint8_t cast on sizeof(buf) in nRF24 payload length guard
    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
    [main.cpp]
2026-04-30 Update nRF24 SPI pins to GPIO1/GPIO21
2026-05-14 Switch OLED display from SH1106 128x64 to SH1107 128x128
    Use SH1107 SEEED variant to avoid column-mapping wrap artifacts, update
    layout for 128px height with centered splash/listening text, and switch
    upload protocol to esptool.
    [main.cpp]
2026-05-14 Add KiCad hardware files and README
    - RfGateway KiCad project: schematic, PCB layout, project files, gerbers
    - BOM CSV for RF gateway board
    - README.md with wiring table, build commands, and architecture overview
    [RfGateway.kicad_pcb, RfGateway.kicad_sch, RfGateway_BOM.csv]
2026-10-05 Receive fixed-code 433 MHz remotes on CC1101
    Switch the CC1101 from packet mode (ATtiny3226 link) to async OOK direct
    mode so GDO0 outputs the raw demodulated signal, and decode EV1527/PT2262
    pulse timings with rc-switch. Cheap remotes don't use a sync word or CRC,
    so packet mode can't receive them.
    - Widen RX bandwidth to 270 kHz for remote frequency drift; 9.6 kbps
    - Collapse repeated frames of one button press (same code within 300 ms)
    - OLED shows code hex plus protocol/bits/pulse; serial logs full details
    - ATtiny packet reception removed; nRF24 path unchanged
    [main.cpp]
2026-10-05 Publish RF events to MQTT for Home Assistant
    Connect over Wi-Fi to an MQTT broker so remote presses and nRF24 packets
    can drive Home Assistant automations.
    - rfgateway/remote: JSON {code,bits,protocol,pulse,rssi} per remote press
    - nrf/message: raw packet text, same format as the legacy nrf_receiver
    firmware so existing HA automations keep working
    - rfgateway/status: retained online/offline via LWT
    - HA MQTT discovery for "Last remote code" / "Last nRF24 packet" sensors
    - Non-blocking: radios start immediately, broker retried every 5 s
    - Credentials in gitignored include/secrets.h; secrets.example.h template
    committed, build fails with a clear #error if secrets.h is missing
    Co-Authored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
    [main.cpp]
2026-10-05 Redesign OLED as status header plus rolling message log
    Replace the single-packet detail view with a layout that shows device
    state and recent history at a glance:
    - Header: IP address (or "Wi-Fi connecting..."), filled/hollow dots for
    Wi-Fi and MQTT, live HH:MM:SS clock
    - Log: last 10 messages as "HH:MM:SS <content>", newest row inverted;
    remotes shown as "RF <code>", nRF24 text unprefixed and cut at the
    first NUL so 32-byte padding doesn't render as dots
    - Time from NTP in the Sydney timezone (AEST/AEDT handled by POSIX TZ);
    "--:--:--" until synced
    - Redraw on new messages and once per second
    - Display rotated 270 degrees (U8G2_R3) to match the enclosure
    RSSI/protocol details mov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
    [main.cpp]
2026-10-05 Recover nRF24 after brownout resets
    On this hardware the nRF24 module resets itself to power-on defaults
    under supply dips (observed every 1-2 packets while traffic flows):
    CONFIG 0x08 (powered down), 2 Mbps, RX payload width 0. Reception then
    stops silently until reboot, while the CC1101 keeps working.
    Check getDataRate() every second; anything other than the configured
    250 kbps means the chip was reset, so re-apply the configuration via
    the new initNrf24() (shared with setup()) and log a warning.
    This is mitigation; the root fix is decoupling the module's supply
    (10-100 uF + 100 nF across VCC/GND).
    [main.cpp]
